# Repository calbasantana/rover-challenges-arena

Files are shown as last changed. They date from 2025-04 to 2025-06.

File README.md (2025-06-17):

# Introduction

<p align="center">
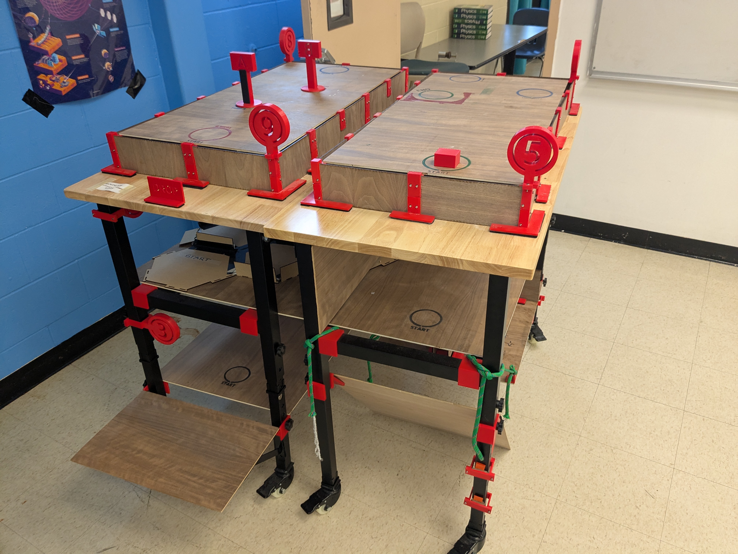
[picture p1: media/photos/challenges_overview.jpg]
Challenges Overview

</p>

Over the past year, I have modified my introductory physics curriculum after experiencing FIRST Lego League (FLL) through the lens of a coach. In FLL, students are tasked with completing a series of challenges, for which they earn points, using a Lego robot in autonomous mode. In previous years, students had constructed a rover capable of navigating autonomously and completed one of the challenges laid out here (challenge 4 -- the maze challenge).

Now, however, thanks to my FLL experiences, I have expanded from one challenge to ten total challenges. This resulted in the creation of a Rover Challenges Arena, which will be described here in detail. Specifically, I will highlight:

* The construction of the arena
* The challenges themselves

Below you will find resources associated with this course and repository.

**Associated Resources**:
* [Introductory Physics Google Drive folder](https://drive.google.com/drive/folders/14O6FQSpFUbI4DR4CiFaPI4PMuGjOlXuQ?usp=drive_link)
* [Rover Repository](https://github.com/calbasantana/rover)

# Challenges Arena Construction
The Challenges Arena was constructed with the aid of a lasercutter, 3D printer, and hand saw. Below you will find the complete list of materials used.

## Material(s)

**Challenges Arena**

* [2 48" Heavy-Duty Workbenches ($134.99 each, $269.98 total)](https://www.amazon.com/Betterhood-Heavy-Duty-Adjustable-Workstation-Wheels/dp/B09VXCW6VS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)
* [4 Sets of 8-Pack 12" x 16" x 1/8" Walnut Plywood Sheets ($32.99 each, or $131.96 total)](https://www.amazon.com/ROBOTIME-16-Pack-Walnut-Plywood-Sheets/dp/B0D4QWKYR7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)
* [4 True Red ELEGOO 1kg, 1.75mm Filament ($17.99 each, or $71.96 total)](https://www.amazon.com/ELEGOO-Filament-Dimensional-Accuracy-Printers/dp/B0D41ZDXLR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)
* [3 PureBond 4' x 4' Walnut Plywood Project Panels ($86.99 each, or $260.67 total)](https://www.homedepot.com/p/Columbia-Forest-Products-1-4-in-x-4-ft-x-4-ft-PureBond-Walnut-Plywood-Project-Panel-Free-Custom-Cut-Available-2328/204635499)
* [1/8" 11" x 17" Corrugated Cardboard Sheets ($29.99)](https://www.amazon.com/Golden-State-Art-Corrugated-Cardboard/dp/B09KYGZX8F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)
* [3 Sets of Double-Sided 1" x 4" Double-Sided Adhesive Strip ($11.39 each, or $34.17 total)](https://www.amazon.com/Art3d-Sticky-Double-Sided-Command-Adhesive/dp/B0B58FKYR2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)
* [Braided Rope ($9.99)](https://www.amazon.com/MaxxHaul-50227-Strength-Sunlight-Resistant-Multicolor/dp/B07X64Z69L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)
* [2 Triangle Shelf Brackets ($9.49)](https://www.amazon.com/Dewell-Triangle-Brackets-Mounted-Supports/dp/B07QLK6PWS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)

**Challenge 2: How Far? Surface Friction Materials**

For Challenge 2: How Far?, I also bought two types of materials, which I cut up and attached using velcro to the inner sides of the challenge to simulate friction versus different materials. I left a few sheets of each material as spare material for students to use for finding the coefficients of friction. Here is what I bought:

* [8.5"x11" 1/8" Thick Corrugated Cardboard Sheets ($14.89)](https://www.amazon.com/Corrugated-Cardboard-Shipping-Cushioning-Packing/dp/B09JQ6KPGB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)
* [9"x11" 120 Grit Sandpaper Sheets ($12.42)](https://www.amazon.com/Sungold-Abrasives-11108-Stearated-Aluminum/dp/B005YUJM3C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)
* [VELCRO Fasteners ($18.89)](https://www.amazon.com/VELCRO-Brand-Sticky-Fasteners-Perfect/dp/B000GRBEK2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)

Please note that I did three strips of Velcro, as shown below:

<p align="center">
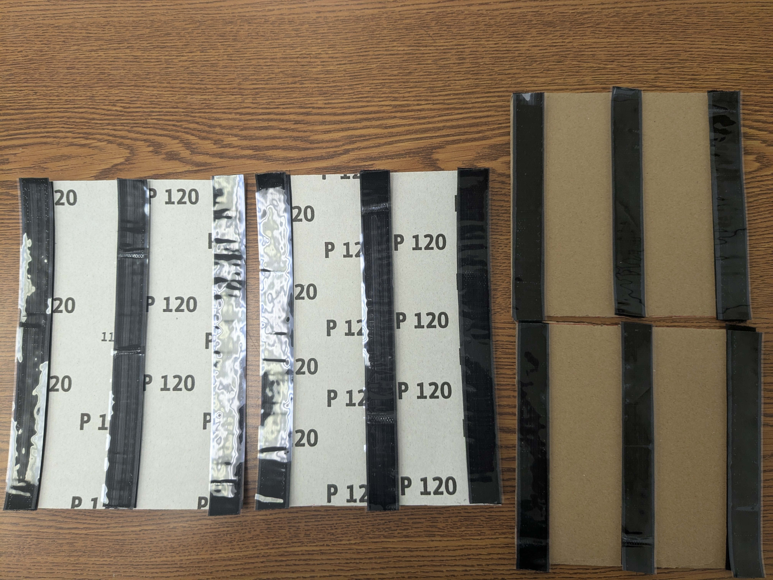
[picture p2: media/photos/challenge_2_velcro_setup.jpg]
Challenge 2 Velcro Setup

</p>

**Challenge 5: Surface Navigation Terrain**

For Challenge 5: Surface Navigation, I made a model of the lunar surface because I wanted students to experience navigating difficult terrain; to create this, I used the following materials:

* [10lb Large Black Lava Rocks ($29.99)](https://www.amazon.com/Onlyfire-Granules-Decorative-Outdoor-Fireplaces/dp/B0BPL24PYG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)
* [5 Bags of Medium (1/2" - 1") Lava Rocks ($12.35 each, or $61.75 total)](https://www.amazon.com/American-Fireglass-Medium-Lava-Rock/dp/B002NHW0NS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)
* [5 Bags of 4 lb Organic Whole Grain Buckwheat Flour ($20.99 each, or $104.95 total)](https://www.amazon.com/Organic-Buckwheat-Flour-Pounds-Unbleached/dp/B074S7NVH7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)
* [10 lb Unbleached All Purpose Flour ($10.49)](https://www.amazon.com/Gold-Medal-Unbleached-Flour-160-Ounce/dp/B0032A0G3G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)
* [4 Bags of 1.5lb Gray Unity Sand ($16.99 each, or $67.96 total)
](https://www.amazon.com/Sandsational-Sand-1-5-Colored-Weddings-Filler/dp/B00GMRPU46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)

**Screws and Nuts**

* [M3 x 10mm Socket Head Cap Screws ($7.69)](https://www.amazon.com/Fullerkreg-Socket-Stainless-Machine-Quantity/dp/B07CK3RSN3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)
* [M3 Locknuts ($5.99)](https://www.amazon.com/M3-Locknuts-Self-Lock-Stainless-Self/dp/B0D146SHYF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)

**Spray Painting**

I decided to use spray paint for the stencils, although in retrospect, it may have been easier to use acrylic paint since many of the numbers didn't come out as well as I wanted to. Here is the spray painting equipment I used:

* [Rust-Oleum Black Camouflage Spray Paint ($6.98)](https://www.homedepot.com/p/Rust-Oleum-Specialty-12-oz-Black-Camouflage-Spray-Paint-279179/326885188)
* [Rust-Oleum Gloss Colonial Red Spray Paint ($6.48)](https://www.homedepot.com/p/Rust-Oleum-Painter-s-Touch-2X-12-oz-Gloss-Colonial-Red-General-Purpose-Spray-Paint-334030/307244800)
* [Rust-Oleum Gloss Hunter Green Spray Paint ($6.48)](https://www.homedepot.com/p/Rust-Oleum-Painter-s-Touch-2X-12-oz-Gloss-Hunter-Green-General-Purpose-Spray-Paint-334034/307244781)
* [Rust-Oleum Satin Ink Blue Spray Paint ($6.48)](https://www.homedepot.com/p/Rust-Oleum-Painter-s-Touch-2X-12-oz-Satin-Ink-Blue-General-Purpose-Spray-Paint-334093/307244914)
* [3M Professional Paint Spray Respirator Medium ($48.98)](https://www.homedepot.com/p/3M-Professional-Paint-Spray-Respirator-Medium-7512PA1-A-PS/202077812)

## CAD Model

<p align="center">
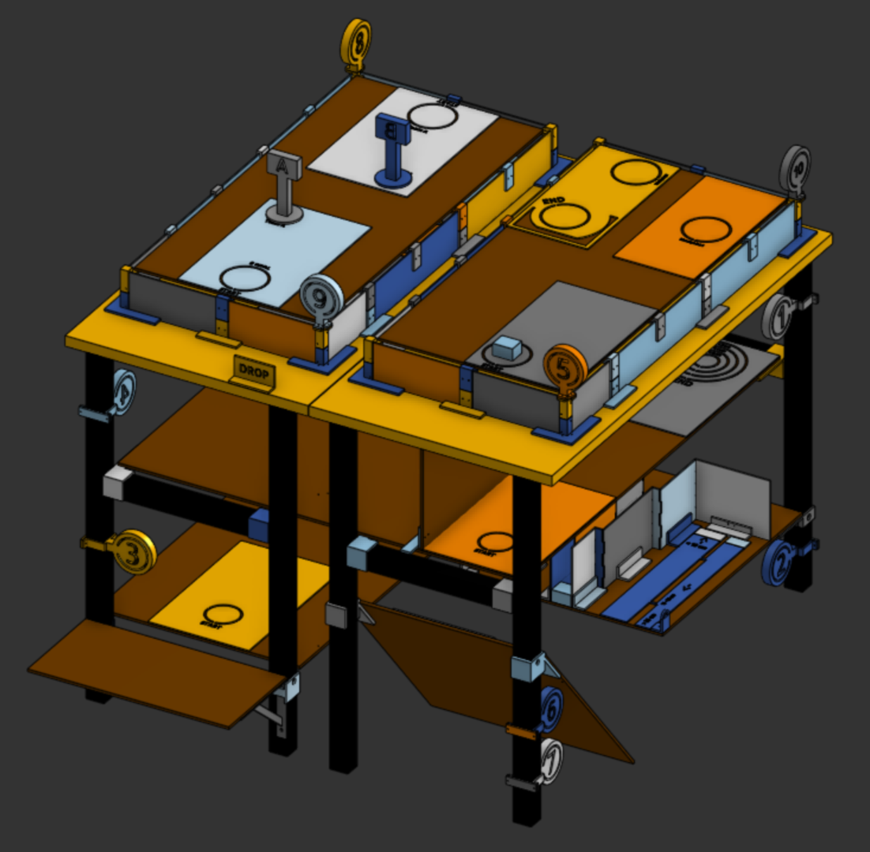
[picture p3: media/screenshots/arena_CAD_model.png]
Challenges Arena CAD Model

</p>

The fully completed CAD model is included above. It is important to note that there are over 150 parts to this design, so there will be a lot that needs to be lasercut and 3D printed. It is my largest project as of writing. Nevertheless, I do hope that the organization of the folders will make it easier to manufacture the components for this.

## 3D-Printed Parts
All parts that need to be 3D printed will be inside folders called "3D Prints", which will be inside each of the challenge's main folder.

### 3D Printing Process
The 3D printing process is quite lengthy given the large number of parts. However, expect around ~3 weeks of continuous printing to print all parts necessary for this project. The material used was included the previous materials section (True Red PLA from ELEGOO). Below you will find more information regarding the printer and settings used.

#### 3D Printer
Original Prusa Mini+

#### Software
PrusaSlicer

#### Settings
Layer Height: .2mm \
Infill: 50% \
Supports: Everywhere \
Estimated Printing Time: ~ 3 weeks.

## Laser Cut Parts
For the laser cut parts, which can be found in two separate folders -- "Laser Cuts" for parts that will be cut from the walnut sheets and "Stencils" for those that will be cut from the cardboard sheets -- are inside each of the challenge's main folder.

### Laser Cutting Process
Luckily, it is much quicker to fully cut all parts that need to be laser cut for this challenges arena. Make sure to remember to use cardboard for the stencils.

#### Lasercutter
XTool D1 Pro

#### Software
XTool Creative Studio (XCS)

#### Settings (for cutting)
Power (%): 100 \
Speed (mm/s): 5 \
Pass: 1

## Hand Sawn Parts
The last set of parts are those that need to be sawn. I purchased the large walnut sheets from Home Depot and got someone there to saw most of them for me. For the small parts, I used a hand saw. Below are the dimensions required:

* 1 44" x 40"
* 1 44" x 20"
* 1 44" x 10"
* 2 38" x 18.5"
* 2 24" x 20"
* 1 20" x 10"

Once you have finished these parts, you will be ready to use the stencils and spray paint.

## Stencils and Spray Painting

<p align="center">
  Spray Painting Photo 1
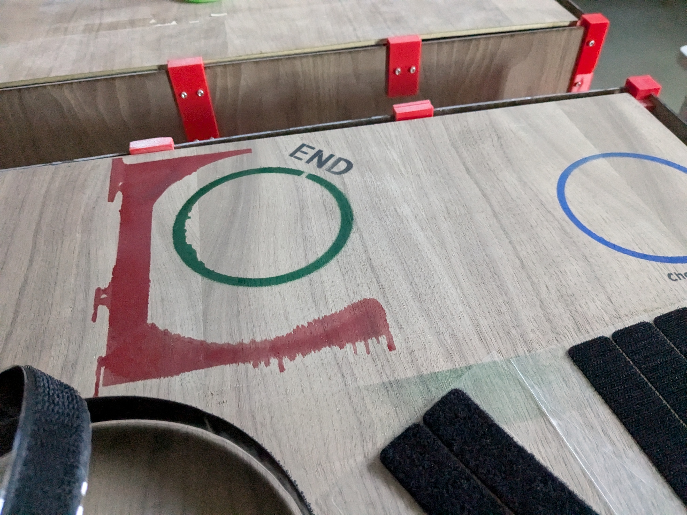
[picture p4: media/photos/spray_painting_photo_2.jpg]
Spray Painting Photo 2
  
</p>

For spray painting, I went outside on a nice cool day and began color coding things. You might do things differently, but you can tell from the pictures of the challenges how I decided to color things. In retrospect, as I mentioned before, I think I should have opted for acrylic paint because some of the spray paint didn't stick too well or bled out too much into the wood grain.

## Assembly
Once all parts have been completed and relevant parts spray painted, it's time for assembly. I highly suggest building the middle layer first so you can connect the large walnut sheet across both tables, which will provide some stability as you go on to assemble the rest. I expct assembly to take a full day or two given all the parts and screwing of components required.

For Challenge 5: Surface Navigation, I recommend adding some tape along the walls so the mixture doesn't seep through easily. You can include as many or as few rocks as you would like. I recommend using the medium-sized rocks all throughout the surface and the larger rocks for Challenge 1: Hercules's Push and maybe a few spread out on the Challenge 5: Surface Navigation.

# Challenges Overview
This part is the most relevant for students as it relates to what each challenge is specifically asking, so some students viewing this repository might want to skip to this section. For each challenge, there is an **Engineering Component** and a **Physics Component**. Students will be awarded points based on both the physical completion of the challenge (the former) and the completion of the mini-lab associated with it (the latter).

**IMPORTANT**: Students are required to complete a minimum of two **engineering components** and two **physics components** successfully. This should be done in the following manner, assuming students A, B, C, and D are in a group together.

**Challenge 1**

* Students A and B complete the engineering component together.
* Students C and D complete the physics component together.

**Challenge 2**

* Students C and D complete the engineering component together.
* Students A and B complete the physics component together.

Essentially, each pair of students will each complete one engineering component together and one physics component together. Students will receive credit for the engineering component they completed with their primary partner.

A complete description of each challenge will be found below. Please note that the maximum number of points possible is 800, but teams average around 100-200 historically.

## Challenge 1: Hercules's Push

<p align="center">
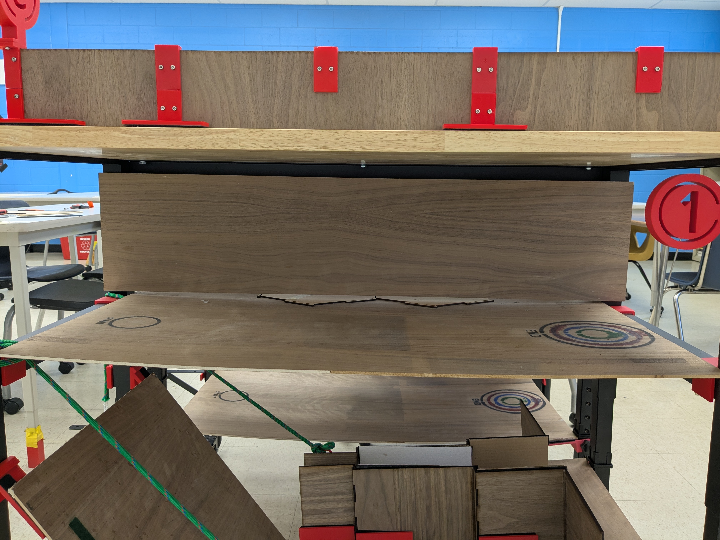
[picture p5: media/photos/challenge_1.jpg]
Challenge 1

</p>

**Engineering Component**

For this challenge, students are tasked with pushing a lava rock from one end of the field to the other. Points are determined based on accuracy to the target location as shown below:

| Distance from Target | Points Awarded |
| --- | --- |
| Not Attempted  | 0  |
| <2cm  | 20  |
| <4cm  | 15  |
| <6cm  | 5  |

**Physics Component**

This challenge requires students to be familiar with kinematics (as well as forces) concepts and coding in micropython, as they will be required to:

* Program their rover so that it has constant acceleration
* Use a kinematic equation to determine the push and net accelerations of their rover
* Create force diagrams for the lava rock
* Determine force of friction on the lava rock

More details on how students are graded for this can be found in the assignment itself, which is under Documents in Challenge 1: Hercules's Push folder. The document is listed as docx and PDF files.

The grading rubric, which is the same for all challenges, is included below:

| Proficiency Level | Points Awarded | Grade |
| --- | --- | --- |
| **Not Yet**: You have not correctly completed any of the elements of this challenge component. | 0 | 50% |
| **Approaching Proficiency**: You have correctly completed at least one element of this challenge component. | 10 | 60% |
| **Somewhat Proficient**: You have correctly completed half of the elements of this challenge component. | 20 | 70% |
| **Proficient**: You have correctly completed all of the elements of this challenge component. | 30 | 85% |
| **Exceeding Proficiency**: You have additionally and correctly completed the independent element of this challenge component.  | 40 | 100% |

**Student Example**

This was a very easy challenge for most students to complete, so you will be able to see two video examples below (as well as under media/videos).

https://github.com/user-attachments/assets/afdffd39-8b7c-4cd7-a783-8676905cb639

https://github.com/user-attachments/assets/8b72730f-63d5-43e9-9725-9e6176717091

## Challenge 2: How Far?

<p align="center">
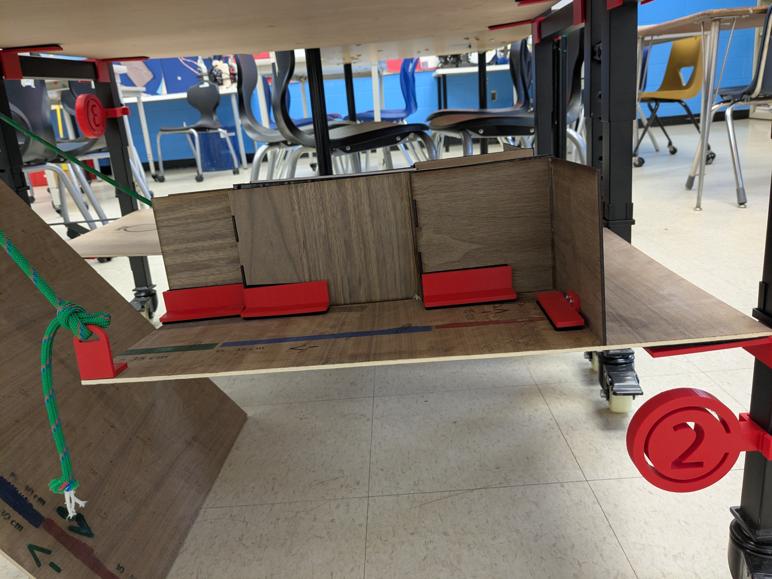
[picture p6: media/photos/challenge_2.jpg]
Challenge 2

</p>

**Engineering Component**

This can be one of the trickier challenges to complete depending on how you do it. It requires students to design the rover such that it can push a 3cm x 4cm x 5cm box through an increasingly smaller opening. The first opening is 13cm wide, the second is 9cm wide, and the last is 5cm wide. It must go all the way through and push the box over the edge on the smaller side of the challenge field. Depending on how far you make it, you will be awarded a different number of points, as shown below.

| Distance Traveled | Points Awarded |
| --- | --- |
| Not Attempted  | 0 |
| <15cm  | 20 |
| 15-30cm  | 15 |
| >30cm  | 5 |

**Physics Component**

This challenge requires students to be familiar with forces concepts and coding in micropython, as they will be required to:

* Determine coefficient of friction between their rover material and challenge-specific materials
* Answer questions about friction

More details on how students are graded for this can be found in the assignment itself, which is under Documents in Challenge 2: How Far? folder. The document is listed as docx and PDF files.

The grading rubric, which is the same for all challenges, is included below:

| Proficiency Level | Points Awarded | Grade |
| --- | --- | --- |
| **Not Yet**: You have not correctly completed any of the elements of this challenge component. | 0 | 50% |
| **Approaching Proficiency**: You have correctly completed at least one element of this challenge component. | 10 | 60% |
| **Somewhat Proficient**: You have correctly completed half of the elements of this challenge component. | 20 | 70% |
| **Proficient**: You have correctly completed all of the elements of this challenge component. | 30 | 85% |
| **Exceeding Proficiency**: You have additionally and correctly completed the independent element of this challenge component.  | 40 | 100% |

**Student Example**

For this challenge, you can see below and under media/videos how a team of students was able to complete it. However, please note that students will no longer be allowed to use an additional field to extend the length and reach of their attachments.

https://github.com/user-attachments/assets/25190a58-6e21-4ddf-ae70-2b8eacff4d61

## Challenge 3: A Rocky Landing

<p align="center">
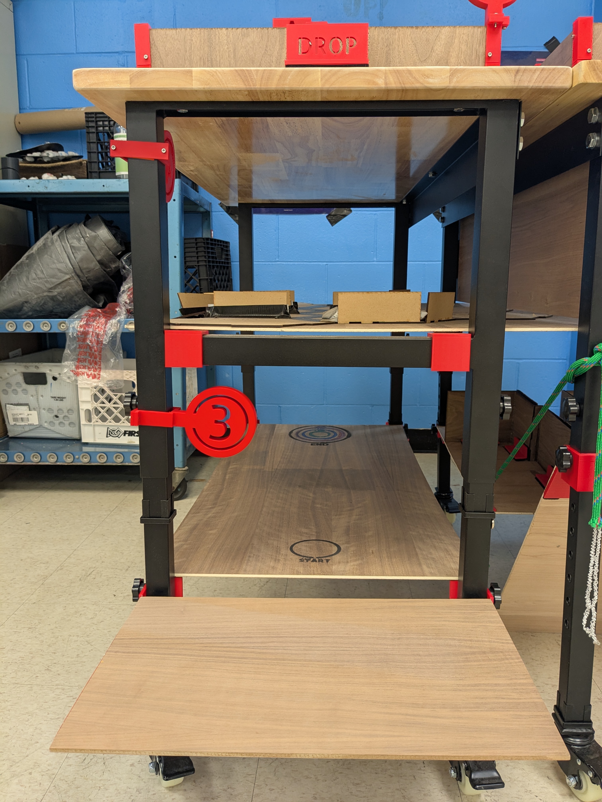
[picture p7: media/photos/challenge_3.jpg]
Challenge 3

</p>

**Engineering Component**

This is the one challenge that very few students have attempted and none have succeeded as of writing this. It requires for the rover to be dropped from a height of approximately .75 meters and subsequently navigate to a target location. Points are awarded based on accuracy of the location to the target as shown below.

| Distance from Target | Points Awarded |
| --- | --- |
| Not Attempted  | 0 |
| <2cm  | 20 |
| <4cm  | 15 |
| <6cm  | 5 |

**Physics Component**

This challenge requires students to be familiar with energy and law of conservation of energy concepts and coding in micropython, as they will be required to:

* Calculate gravitational potential energy and kinetic energy
* Determine how much energy the rover system would need to absorb
* Answer questions about energy

More details on how students are graded for this can be found in the assignment itself, which is under Documents in Challenge 3: A Rocky Landing folder. The document is listed as docx and PDF files.

The grading rubric, which is the same for all challenges, is included below:

| Proficiency Level | Points Awarded | Grade |
| --- | --- | --- |
| **Not Yet**: You have not correctly completed any of the elements of this challenge component. | 0 | 50% |
| **Approaching Proficiency**: You have correctly completed at least one element of this challenge component. | 10 | 60% |
| **Somewhat Proficient**: You have correctly completed half of the elements of this challenge component. | 20 | 70% |
| **Proficient**: You have correctly completed all of the elements of this challenge component. | 30 | 85% |
| **Exceeding Proficiency**: You have additionally and correctly completed the independent element of this challenge component.  | 40 | 100% |

**Student Example**

At time of writing, there has yet to be a team to complete this challenge. It is incredibly difficult.

## Challenge 4: A Way Out

<p align="center">
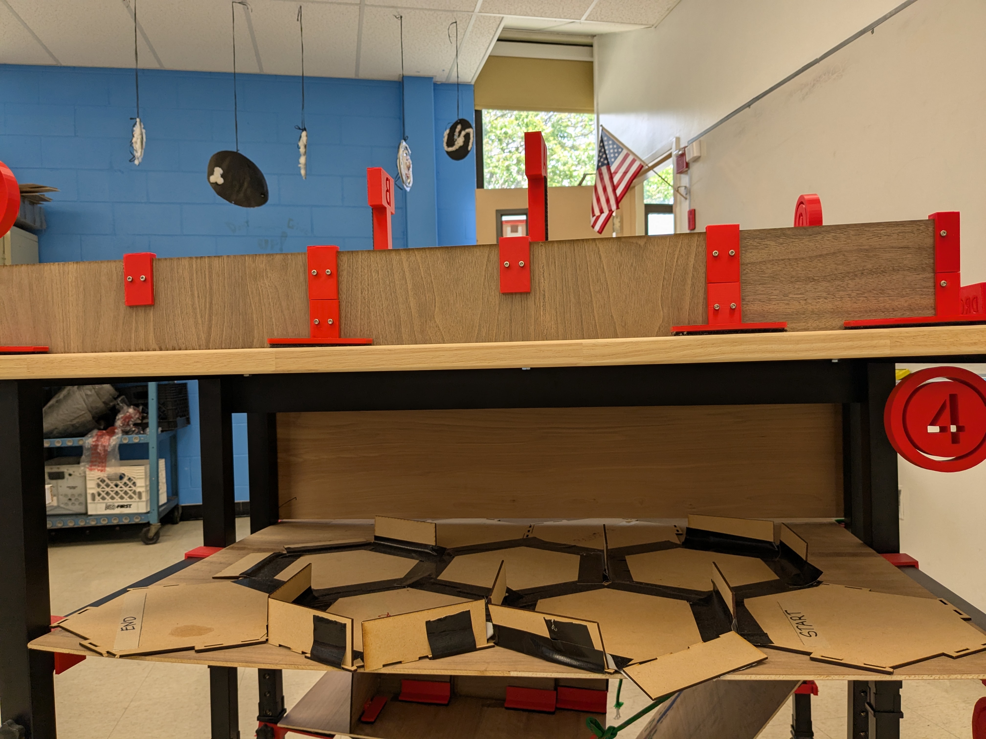
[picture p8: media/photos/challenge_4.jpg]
Challenge 4

</p>

**Engineering Component**

This challenge is different than the previous challenges because points are awarded based on the completion of certain tasks, rather than accuracy. Specifically, students are required to navigate a maze and will only receive points if they complete the maze. They will receive additional points if they have their rover pass through "Bonus" sections. Below is a breakdown of the number of points per task.

| Task | Points Awarded |
| --- | --- |
| Not Attempted  | 0 |
| Maze Completion  | 30 |
| Bonus 1  | 15 |
| Bonus 2  | 15 |

Please note that this means, based on the engineering component alone, students can earn up to 60 points, much greater than the previous challenges's engineering components.

**Physics Component**

This challenge requires students to be familiar with kinematics concepts and coding in micropython, as they will be required to:

* Determine the total distance traveled by their rover
* Determine the average speed of their rover
* Determine the displacement of their rover
* Determine the average velocity of their rover

More details on how students are graded for this can be found in the assignment itself, which is under Documents in Challenge 4: A Way Out folder. The document is listed as docx and PDF files.

The grading rubric, which is the same for all challenges, is included below:

| Proficiency Level | Points Awarded | Grade |
| --- | --- | --- |
| **Not Yet**: You have not correctly completed any of the elements of this challenge component. | 0 | 50% |
| **Approaching Proficiency**: You have correctly completed at least one element of this challenge component. | 10 | 60% |
| **Somewhat Proficient**: You have correctly completed half of the elements of this challenge component. | 20 | 70% |
| **Proficient**: You have correctly completed all of the elements of this challenge component. | 30 | 85% |
| **Exceeding Proficiency**: You have additionally and correctly completed the independent element of this challenge component.  | 40 | 100% |

**Student Example**

Unfortunately, I do not presently have a video to show here, but one team has completed this challenge in the past. Please note that the most difficult element of completing this challenge is the coding, which will require a lot of trial and error.

## Challenge 5: Surface Navigation

<p align="center">
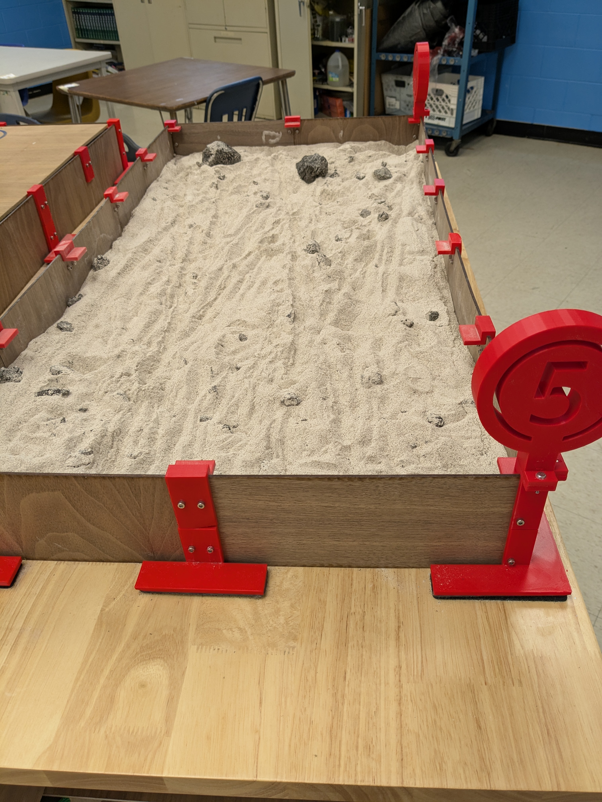
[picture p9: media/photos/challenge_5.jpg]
Challenge 5

</p>

**Engineering Component**

This challenge requires students to design their rover such that it can navigate from one end of the field to the other. Most rovers are designed in such a way that this is very difficult and a lot of teams design custom wheels to support them in completing this challenge. Like the previous challenge, this challenge's points are awarded based on the completion of certain tasks, which will be shown in the rubric below.

| Task | Points Awarded |
| --- | --- |
| Not Attempted  | 0 |
| Navigate to End  | 30 |
| Carry 1 Large Lunar Rock  | 15 |
| Carry 1 Large Lunar Rock  | 15 |

As noted in the previous challenge, this means that a team can earn up to 60 points for navigating from one end to another and carrying two lunar rocks (which are really just the lava rocks from the materials section of the arena).

**Physics Component**

This challenge requires students to be familiar with kinematics concepts and coding in micropython, as they will be required to:

* Determine the displacement of their rover
* Determine the average velocity of their rover
* Determine the acceleration of their rover

More details on how students are graded for this can be found in the assignment itself, which is under Documents in Challenge 5: Surface Navigation folder. The document is listed as docx and PDF files.

The grading rubric, which is the same for all challenges, is included below:

| Proficiency Level  | Points Awarded | Grade |
| --- | --- | --- |
| **Not Yet**: You have not correctly completed any of the elements of this challenge component. | 0 | 50% |
| **Approaching Proficiency**: You have correctly completed at least one element of this challenge component. | 10 | 60% |
| **Somewhat Proficient**: You have correctly completed half of the elements of this challenge component. | 20 | 70% |
| **Proficient**: You have correctly completed all of the elements of this challenge component. | 30 | 85% |
| **Exceeding Proficiency**: You have additionally and correctly completed the independent element of this challenge component.  | 40 | 100% |

**Student Example**

Below and under media/videos you will find a video of how a team completed the engineering component of this challenge.

https://github.com/user-attachments/assets/06d660ac-c105-4a08-b690-703fcb1c7aff

## Challenge 6: Welcome to Seattle

<p align="center">
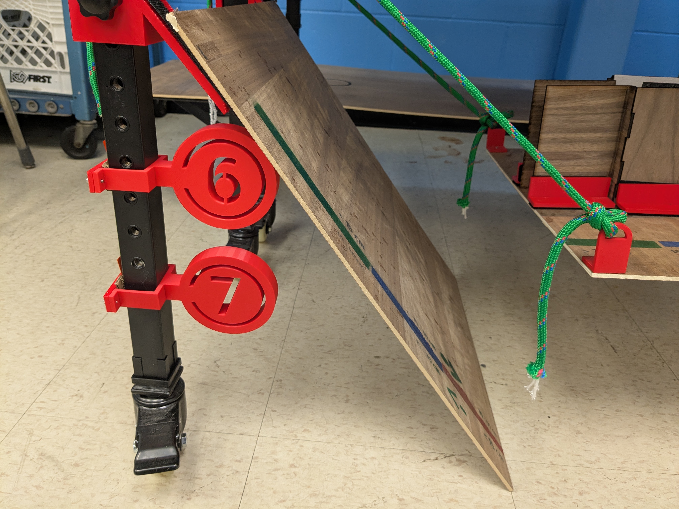
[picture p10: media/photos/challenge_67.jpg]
Challenges 6 and 7

</p>

**Engineering Component**

Seattle is known for being a hilly city and on an escapade a few years back, I learned the lesson the hard way. For this challenge, students are required to have their rover move up a steep incline. They will be awarded points based on how far their rover makes it up the incline; for some rovers, they will only make it part of the way up and then they will fall backwards and for others they will make it over quite easily and fall forward. Either way, points are awarded as shown below.

| Distance Traveled | Points Awarded |
| --- | --- |
| Not Attempted  | 0 |
| <15cm  | 20 |
| 15-30cm  | 15 |
| >30cm  | 5 |

**Physics Component**

This challenge requires students to be familiar with forces concepts primarily, as they will be required to:

* Determine the maximum angle at which their rover can stay still on an incline
* Determine the values of all forces on their rover on an incline plane

More details on how students are graded for this can be found in the assignment itself, which is under Documents in Challenge 6: Welcome to Seattle folder. The document is listed as docx and PDF files.

The grading rubric, which is the same for all challenges, is included below:

| Proficiency Level  | Points Awarded | Grade |
| --- | --- | --- |
| **Not Yet**: You have not correctly completed any of the elements of this challenge component. | 0 | 50% |
| **Approaching Proficiency**: You have correctly completed at least one element of this challenge component. | 10 | 60% |
| **Somewhat Proficient**: You have correctly completed half of the elements of this challenge component. | 20 | 70% |
| **Proficient**: You have correctly completed all of the elements of this challenge component. | 30 | 85% |
| **Exceeding Proficiency**: You have additionally and correctly completed the independent element of this challenge component.  | 40 | 100% |

**Student Example**

As of yet, there has not been a single team who has completed this challenge, though many have tried; unfortunately, there is no student example to show here.

## Challenge 7: Down the Canyon

<p align="center">
Challenges 6 and 7
</p>

**Engineering Component**

This challenge is a sister challenge to the previous in that it is using the same arena, but instead of going up the incline, you are going down the incline. The trick here is ensuring that your rover does not slip and fall as it is going down. Points will also be awarded in a similar way, but it is distance from the top to the bottom; see the rubric below for the breakdown and specifics.

| Distance Traveled | Points Awarded |
| --- | --- |
| Not Attempted  | 0 |
| <15cm  | 20 |
| 15-30cm  | 15 |
| >30cm  | 5 |

**Physics Component**

Like the previous challenge, students will need to be familiar with forces primarily because this challenge will require them to:

* Determine the value of the friction force on your rover on an incline plane
* Determine the work done by friction

More details on how students are graded for this can be found in the assignment itself, which is under Documents in Challenge 1: Hercules's Push folder. The document is listed as docx and PDF files.

The grading rubric, which is the same for all challenges, is included below:

| Proficiency Level  | Points Awarded | Grade |
| --- | --- | --- |
| **Not Yet**: You have not correctly completed any of the elements of this challenge component. | 0 | 50% |
| **Approaching Proficiency**: You have correctly completed at least one element of this challenge component. | 10 | 60% |
| **Somewhat Proficient**: You have correctly completed half of the elements of this challenge component. | 20 | 70% |
| **Proficient**: You have correctly completed all of the elements of this challenge component. | 30 | 85% |
| **Exceeding Proficiency**: You have additionally and correctly completed the independent element of this challenge component.  | 40 | 100% |

**Student Example**

I currently do not have a video of this challenge being completed, but one group has completed in the past and three have attempted it.

## Challenge 8: Giving a Gift

<p align="center">
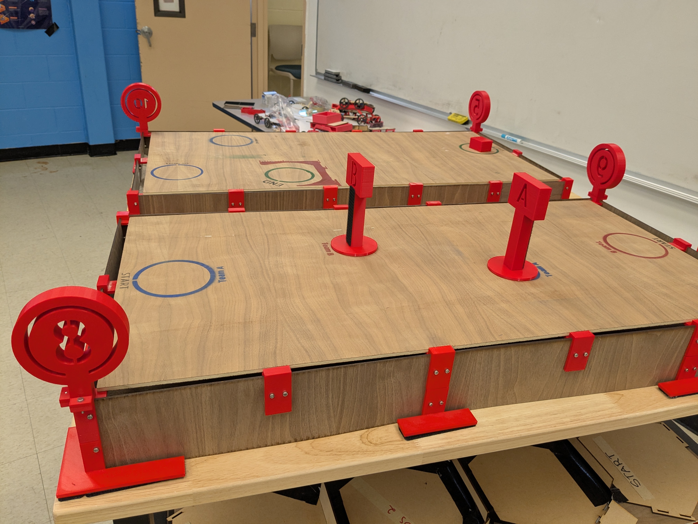
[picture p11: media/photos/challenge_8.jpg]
Challenge 8

</p>

**Engineering Component**

This, and the subsequent two challenges, are considered "competition"-style challenges. This means that students will compete against other teams; for two of these challenges, it will be in real time, but for the last one it will be in timed trials.

For this specific challenge, each team places their rover at either end of the field and they are tasked with pushing a flag of the opposing team into the opposing team's base. Essentially, students are tasked with returning flags to the opposing team or -- as the name suggests -- giving them a gift.

This challenge can only run if there are at least three teams taking part in it. If only one or two teams decide to take part, then it isn't much of a competition; for that reason, should there be fewer than three teams competing, then both teams, or the single team competing, will receive points that would typically be awarded to those in second place.

Based on placement in the competition, the points awarded will be as described in the table below.

| Placement | Points Awarded |
| --- | --- |
| Not Attempted | 0 |
| First Place | 60 |
| Second Place | 30 |
| Third Place | 15 |

**Physics Component**

This challenge requires students to be familiar with momentum (as well as the law of conservation of momentum) concepts and coding in micropython, as they will be required to:

* Determine initial momentum of the system
* Determine final momentum of the system
* Determine how much momentum is lost and why

However, students should note that -- at least in my classes -- momentum and the law of conservation of momentum are only covered in the honors version of the course, meaning that to complete the physics component of this challenge, if they do not have the prerequisite background, they will need to learn it on their own or with aid of PositivePhysics.

More details on how students are graded for this can be found in the assignment itself, which is under Documents in Challenge 1: Hercules's Push folder. The document is listed as docx and PDF files.

The grading rubric, which is the same for all challenges, is included below:

| Proficiency Level  | Points Awarded | Grade |
| --- | --- | --- |
| **Not Yet**: You have not correctly completed any of the elements of this challenge component. | 0 | 50% |
| **Approaching Proficiency**: You have correctly completed at least one element of this challenge component. | 10 | 60% |
| **Somewhat Proficient**: You have correctly completed half of the elements of this challenge component. | 20 | 70% |
| **Proficient**: You have correctly completed all of the elements of this challenge component. | 30 | 85% |
| **Exceeding Proficiency**: You have additionally and correctly completed the independent element of this challenge component.  | 40 | 100% |

**Student Example**

The last time I ran this, only one team decided to attempt the challenge, so this is the only available video of students completing this challenge that I have; please find this video below and under media/videos.

https://github.com/user-attachments/assets/4569af59-405b-4fd5-b390-9fb119e761e6

## Challenge 9: SUMO

<p align="center">
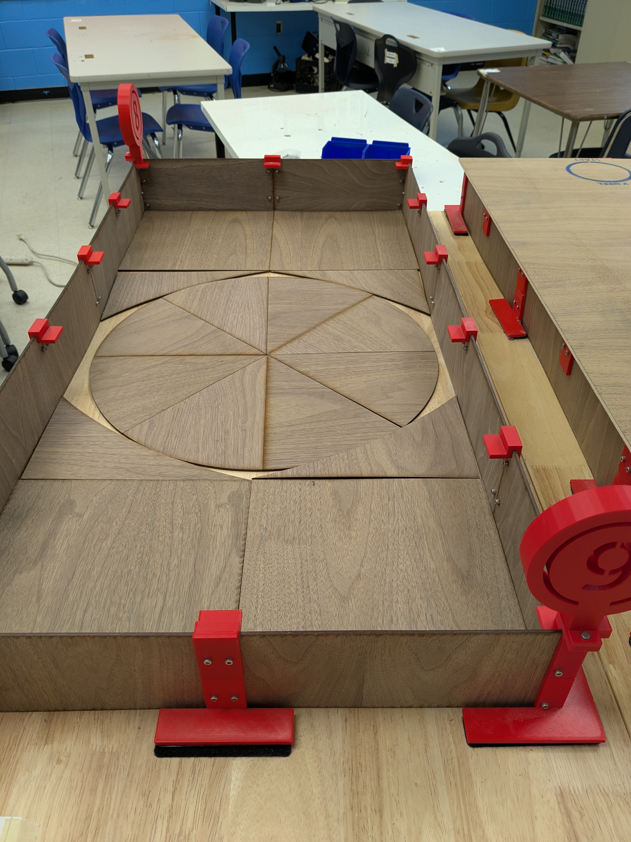
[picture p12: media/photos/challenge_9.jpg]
Challenge 9

</p>

**Engineering Component**

This is probably the most fun and engaging challenge of all; a lot of students choose to compete in this challenge. Much like the previous challenge, it requires a minimum of three teams; if two or fewer sign up, those who sign up will receive points as if they won second place.

For this challenge, the team's rover is required to push the opposing team's rover out of a ring. A team loses when they either get "stuck" on a part of the ring or their rear wheels go outside of the circle. It does not matter what happens after. For a breakdown of points, see the table below.

| Placement | Points Awarded |
| --- | --- |
| Not Attempted | 0 |
| First Place | 60 |
| Second Place | 30 |
| Third Place | 15 |

**Physics Component**

This challenge requires students to be familiar with forces primarily, as they will be required to:

* Collaborate with an opposing team to create a force diagram of your rover and the forces it experiences
* Determine how long it should take to win or lose
* Reflect on accuracy of your calculations

More details on how students are graded for this can be found in the assignment itself, which is under Documents in Challenge 1: Hercules's Push folder. The document is listed as docx and PDF files.

The grading rubric, which is the same for all challenges, is included below:

| Proficiency Level  | Points Awarded | Grade |
| --- | --- | --- |
| **Not Yet**: You have not correctly completed any of the elements of this challenge component. | 0 | 50% |
| **Approaching Proficiency**: You have correctly completed at least one element of this challenge component. | 10 | 60% |
| **Somewhat Proficient**: You have correctly completed half of the elements of this challenge component. | 20 | 70% |
| **Proficient**: You have correctly completed all of the elements of this challenge component. | 30 | 85% |
| **Exceeding Proficiency**: You have additionally and correctly completed the independent element of this challenge component.  | 40 | 100% |

**Student Example**

Below and under media/videos, you will see two of many videos I have of students competing in this challenge.

https://github.com/user-attachments/assets/32562579-a1fd-41d3-9cc3-c7402d23a0af

https://github.com/user-attachments/assets/70a44815-16cc-4bab-8fb9-d8a62cc48f33

## Challenge 10: Resupply Mission

<p align="center">
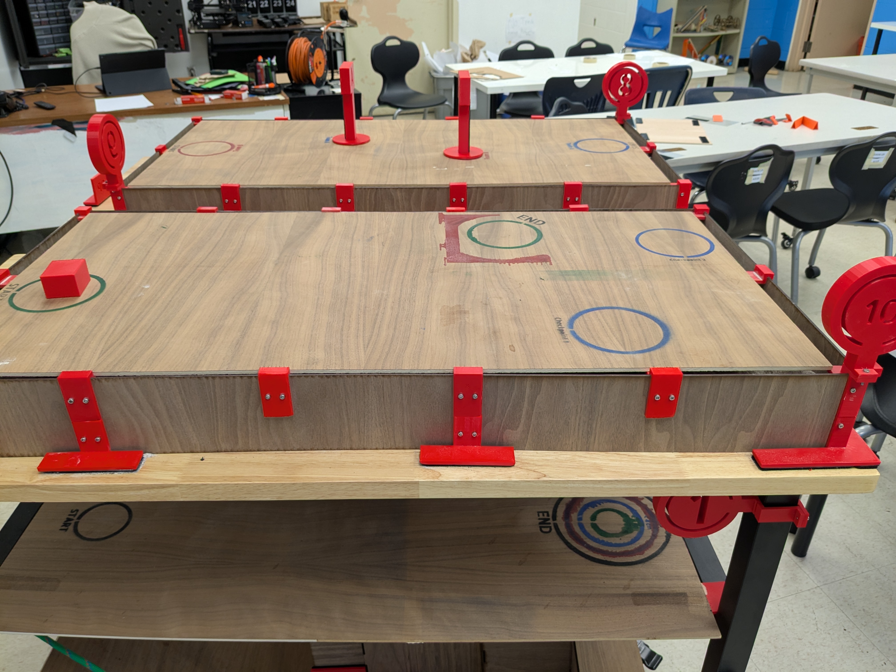
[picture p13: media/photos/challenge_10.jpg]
Challenge 10

</p>

**Engineering Component**

Like the previous two challenges, this last challenge is a "competition"-style challenge. However, what makes this one different than the other two is that it is timed asynchronous trials that will be used to determine placement rather than simultaneous competition.

For this challenge, students are required to have their rover push a box to an endpoint. This endpoint is considered the delivery point. However, students cannot go onto red-colored paint, so they must navigate around to reach the endpoint. The less time it takes for a team to do this, the better; the team with the shortest time to complete this task will receive first place.

However, as noted before, if two or fewer teams sign up for this challenge, then those who complete the challenge will automatically receive points that those who would receive second place in a competition would receive. If three or more teams sign up for this challenge, the points awarded will be the same as the previous competitions (shown below), based on placement.

| Placement | Points Awarded |
| --- | --- |
| Not Attempted | 0 |
| First Place | 60 |
| Second Place | 30 |
| Third Place | 15 |

**Physics Component**

This challenge requires students to be familiar with kinematics (as well as forces)concepts and coding in micropython, as they will be required to:

* Create constant acceleration program
* Create a force diagram for the supply box
* Determine the coefficient of friction of the supply box on the given surface
* Determine how long it should take to move the box to the desired location, based on net force

More details on how students are graded for this can be found in the assignment itself, which is under Documents in Challenge 1: Hercules's Push folder. The document is listed as docx and PDF files.

The grading rubric, which is the same for all challenges, is included below:

| Proficiency Level  | Points Awarded | Grade |
| --- | --- | --- |
| **Not Yet**: You have not correctly completed any of the elements of this challenge component. | 0 | 50% |
| **Approaching Proficiency**: You have correctly completed at least one element of this challenge component. | 10 | 60% |
| **Somewhat Proficient**: You have correctly completed half of the elements of this challenge component. | 20 | 70% |
| **Proficient**: You have correctly completed all of the elements of this challenge component. | 30 | 85% |
| **Exceeding Proficiency**: You have additionally and correctly completed the independent element of this challenge component.  | 40 | 100% |

**Student Example**

In the previous year, only one team signed up to complete this challenge and they were able to complete it successfully. However, I do not have a video of them completing it presently.

# Tips

There is a lot that can be improved regarding these challenges in terms of their physics content, engineering content, and especially the arena itself. Here are some tips that might be helpful.

**Building of the Rover Challenges Arena**

* You can use any type of velcro adhesive, even those that come in big packets and you cut up. It might be cheaper than buying the 1" x 4" strips.
* You do not need as many large lava rocks as I have on the materials list, but they are good in case you want to build something else.

**Challenges**

* Students are encouraged to seek innovative solutions, but it's also OK to rely on the success of previous teams.
* It is generally recommended to pair up challenges such that it is easier to complete and concepts are similar.

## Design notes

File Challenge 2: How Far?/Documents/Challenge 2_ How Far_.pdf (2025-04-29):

Name 1:

Name 2:

Date:

Challenge #2: How Far?

Overview

Up to two students can work on this challenge. Remember each team member must

contribute to at least one the completion of one of the physics components for one challenge and

the completion of one of the engineering components for another challenge. This challenge is

about forces. You will be asked to do the following:

1. Determine coefficient of friction between your rover material and challenge-specific

materials

2. Answer questions about friction

Your Rover Material

You generally have three options regarding the material construction of your rover,

laser-cut MDF wood, laser-cut cardboard, or 3D-printed PLA. Your rover’s exterior, may

however, be made of another material; regardless, please note the exterior material of your rover

that will be making contact with the interior of the tunnel.

Rover Shell Material:

Coefficient of Friction Review

Please remember that, to determine the coefficient of friction, you need to use the

following equation:

Ff=μFN

If you are doing your experiment on a flat surface, then the gravitational force of the

material on top (Fg=mg, where g=9.81 m/s²
) is equal to the normal force (FN). You can also push

one surface against the other, as we did in lab 3, to make sure that the net force experienced is

equal to the force of friction, such that:

Fnet=manet=Ff

In the equation above, m is the mass of the surface on top and the acceleration is

determined either using a kinematic equation or Vernier Video Analysis (the latter of which is

more ideal). You should then be able to determine your coefficient of friction with:

µ =

F
f
F
N
Coefficient of Friction Between Your Rover Material & Interior Material 1

After you have determined your rover shell material, it is time to determine the

coefficient of friction between it and the first interior material for the tunnel. The first layer of

the tunnel is made of cardboard.

In the space below, please draw a force diagram (or free body diagram) of your

experimental set-up to determine the coefficient of friction.

Use Vernier Video Analysis or a kinematic equation to determine your net acceleration

and write it below:

Acceleration (anet): ________

Then, determine the mass (in kg) of the surface on top and subsequently your force of

friction:

Mass (m): ________

Force of Friction (Ff): ________

Using the equation for gravitational force (Fg=mg, where g=9.81 m/s² ), determine your

normal force:

Normal Force (FN): ________

Using the equation for the force of friction (Ff=μFN), determine your coefficient of

friction between these two surfaces.

Coefficient of Friction (μ): ________

Coefficient of Friction Between Your Rover Material & Interior Material 2

You should now attempt to determine the coefficient of friction between your rover shell material

and the second interior material for the tunnel. The second layer of the tunnel is made of

sandpaper.

In the space below, please draw a force diagram (or free body diagram) of your

experimental set-up to determine the coefficient of friction.

Use Vernier Video Analysis or a kinematic equation to determine your net acceleration

and write it below:

Acceleration (anet): ________

Then, determine the mass (in kg) of the surface on top and subsequently your force of

friction:

Mass (m): ________

Force of Friction (Ff): ________

Using the equation for gravitational force (Fg=mg, where g=9.81 m/s² ), determine your

normal force:

Normal Force (FN): ________

Using the equation for the force of friction (Ff=μFN), determine your coefficient of

friction between these two surfaces.

Coefficient of Friction (μ): ________

Coefficient of Friction Between Your Rover Material & Interior Material 3

You should now attempt to determine the coefficient of friction between your rover shell material

and the third interior material for the tunnel. The third layer of the tunnel is made of walnut

plywood.

Exceeding Proficiency: If you determine the coefficient of friction on your own for this section,

and it is correct or reasonable, you will receive exceeding proficiency.

In the space below, please draw a force diagram (or free body diagram) of your

experimental set-up to determine the coefficient of friction.

Use Vernier Video Analysis or a kinematic equation to determine your net acceleration

and write it below:

Acceleration (anet): ________

Then, determine the mass (in kg) of the surface on top and subsequently your force of

friction:

Mass (m): ________

Force of Friction (Ff): ________

Using the equation for gravitational force (Fg=mg, where g=9.81 m/s² ), determine your

normal force:

Normal Force (FN): ________

Using the equation for the force of friction (Ff=μFN), determine your coefficient of

friction between these two surfaces.

Coefficient of Friction (μ): ________

Questions About Friction

There are two types of coefficients of friction, which are they?

Which type of coefficient of friction did you calculate?

Do you expect the coefficient of static friction or the coefficient of kinetic friction to be

higher?

Why did you answer the way you did to the previous question?

Point System (TEACHER ONLY - CIRCLE ONE)

Not Yet (0pts) (50%) | Approaching Proficiency (10pts) (60%) | Somewhat Proficient (20pts) (70%) | Proficient (30pts) (85%) | Exceeding Proficiency (40pts) (100%)
You have not correctly completed any of the elements of this challenge component. | You have correctly completed at least one element of this challenge component. | You have correctly completed half of the elements of this challenge component. | You have correctly completed all of the elements of this challenge component. | You have additionally and correctly completed the independent element of this challenge component.

Comments:

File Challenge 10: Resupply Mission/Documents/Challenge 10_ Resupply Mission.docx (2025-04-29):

Name 1:

Name 2:

Date:

## Challenge #10: Resupply Mission

Overview

Up to two students can work on this challenge. Remember each team member must contribute to at least one the completion of one of the physics components for one challenge and the completion of one of the engineering components for another challenge. This challenge is primarily about kinematics. You will be asked to do the following:

1. Create constant acceleration program
2. Create a force diagram for the supply box
3. Determine the coefficient of friction of the supply box on the given surface
4. Determine how long it should take to move the box to the desired location, based on net force

Programming

To create a program that has a constant acceleration, you must increase its speed at the same rate. To do this, please use the program template below; feel free to modify the “step” size of 100 and the time between steps of 0.5.

for i in range(100,900, +100):

MD1.forwardMOT12(i)

MD2.forwardMOT34(i)

sleep(0.5)

MD1.stopMOT12()

MD2.stopMOT34()

Determining Push and Net Accelerations

Prior to creating a force diagram for the supply box, it is important that you determine your push and net accelerations. The best way to determine the accelerations of your rover is by using Vernier Video Analysis. Make sure to get steady videos with a meter stick in front and that this is on the actual test surface. First, obtain a video without the supply box and then a video with the supply box. Fill out the corresponding sections.

Determining Push Acceleration (No Supply Box)

When you are analyzing the video on Vernier Video Analysis, look at your X Velocity (m/s) vs. Time (s) graph. If you need help to access this graph, please ask your teacher. Select two points that lie on a straight line and determine push acceleration. Make sure to write down:

Initial Velocity (v0): ________

Final Velocity (v): ________

Time (t): ________

Acceleration (apush): ________

Determining Net Acceleration (With Supply Box)

When you are analyzing the video on Vernier Video Analysis, look at your X Velocity (m/s) vs. Time (s) graph. If you need help to access this graph, please ask your teacher. Select two points that lie on a straight line and determine net acceleration. Make sure to write down:

Initial Velocity (v0): ________

Final Velocity (v): ________

Time (t): ________

Acceleration (anet): ________

Force Diagram (or Free Body Diagram)

To create a force diagram, first write down all of the forces present below.

In the space provided draw your force diagram and make sure the magnitude of the forces are relative to each other. Please also include the net force in your force diagram.

Determining Drag or Friction Force

You can determine the force of the push using Newton’s second law (with the mass of the rover). Remember that you know the net force on the supply box as well, which means you can calculate the friction force or drag force on the supply box (hint: Fnet=Fapplied-Ff). Use the space below to write down your calculations and write the final value for the friction force.

Friction Force (Ff): ________

Coefficient of Friction (μ): ________

Exceeding Proficiency: If you, additionally, determine the theoretical time to the desired location on your own, and it is correct or reasonable, you will receive exceeding proficiency.

Theoretical Time to the Desired Location

Rewrite your calculated net acceleration from Vernier Video Analysis below . Remember that you will be starting from rest and measure the distance from the side of the supply box closest to the rover to the desired location and write it below.

Acceleration (anet): ________

Initial Velocity (v0): ________

Distance to Desired Location (Δx): ________

Using a kinematic equation, determine the time you would expect for the supply box to reach the desired location. Include your work in the space below.

Time to Desired Location (t): ________

Experimental Time to Desired Location

Now, starting from the same place, experimentally measure – four times – the time to the desired location and complete the table below.

Trial | Time(s)
Average Time:

How does the experimental time compare to the theoretical time from the previous section?

What might be some sources of error that would lead to a difference between the two times?

Point System (TEACHER ONLY - CIRCLE ONE)

Not Yet (0pts) (50%) | Approaching Proficiency (10pts) (60%) | Somewhat Proficient (20pts) (70%) | Proficient (30pts) (85%) | Exceeding Proficiency (40pts) (100%)
You have not correctly completed any of the elements of this challenge component. | You have correctly completed at least one element of this challenge component. | You have correctly completed half of the elements of this challenge component. | You have correctly completed all of the elements of this challenge component. | You have additionally and correctly completed the independent element of this challenge component.
Comments:

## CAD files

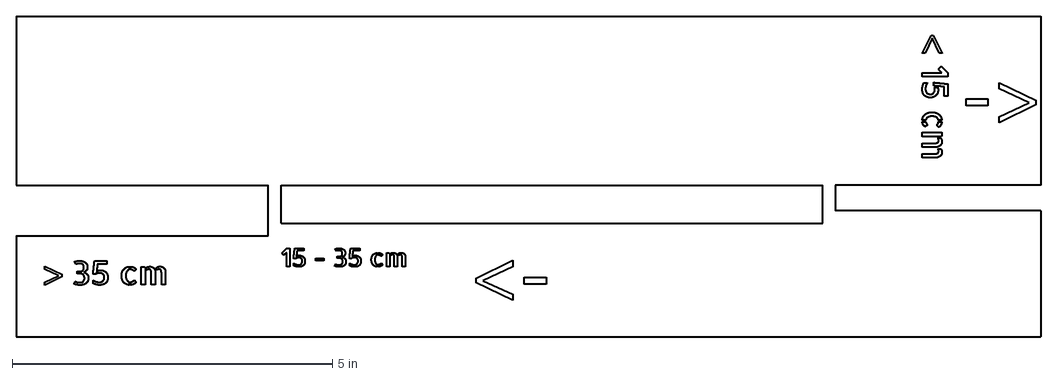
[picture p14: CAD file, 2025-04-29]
Challenge 2: How Far?/Stencils/Challenge 2 Stencil Main.dxf
16.0 x 5.00 in

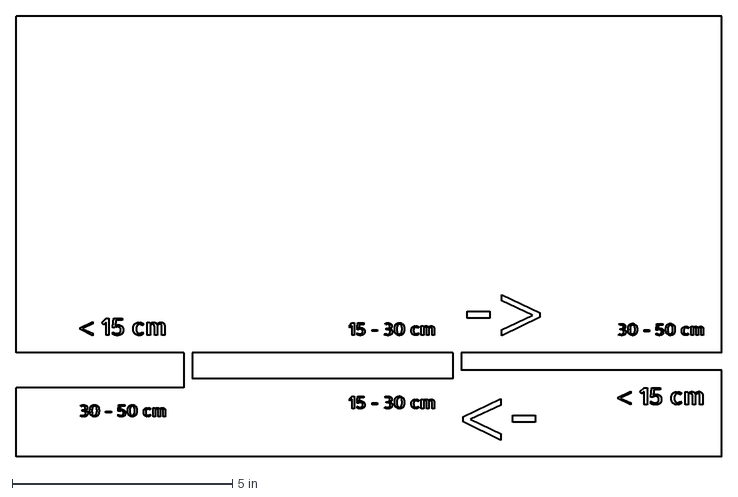
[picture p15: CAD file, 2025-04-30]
Challenge 6: Welcome to Seattle/Stencils/Challenge 6 and 7 Stencil Main.dxf
16.0 x 10.0 in

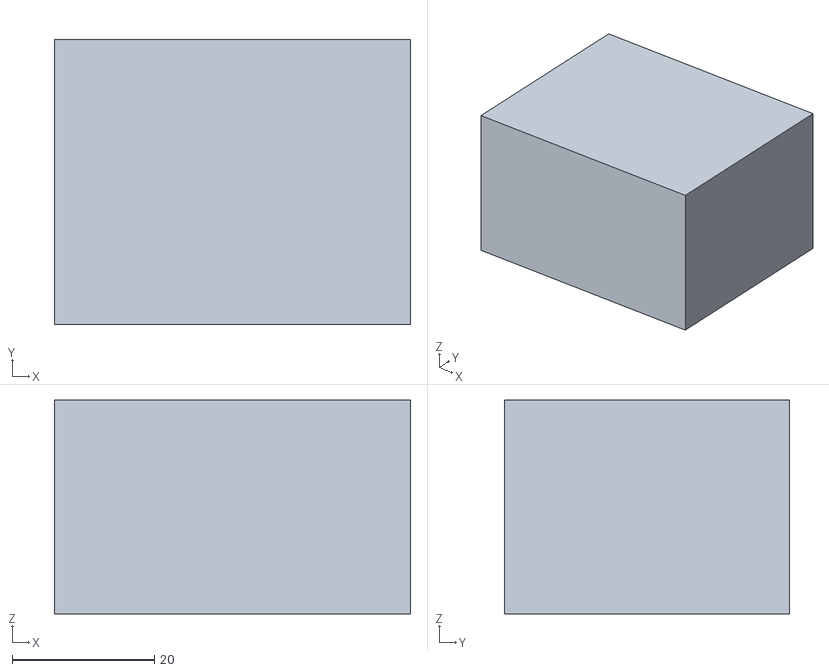
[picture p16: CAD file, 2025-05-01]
Challenge 10: Resupply Mission/3D Prints/Challenge 10 Supply Box.stl
50.0 x 40.0 x 30.0

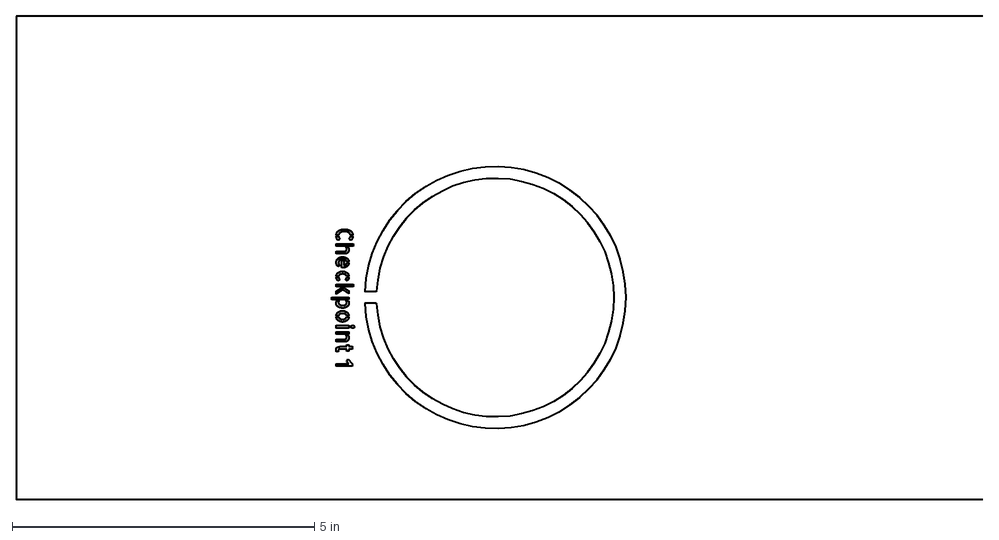
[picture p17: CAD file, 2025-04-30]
Challenge 10: Resupply Mission/Stencils/Challenge 10 Checkpoint 1 Stencil.dxf
16.0 x 8.00 in

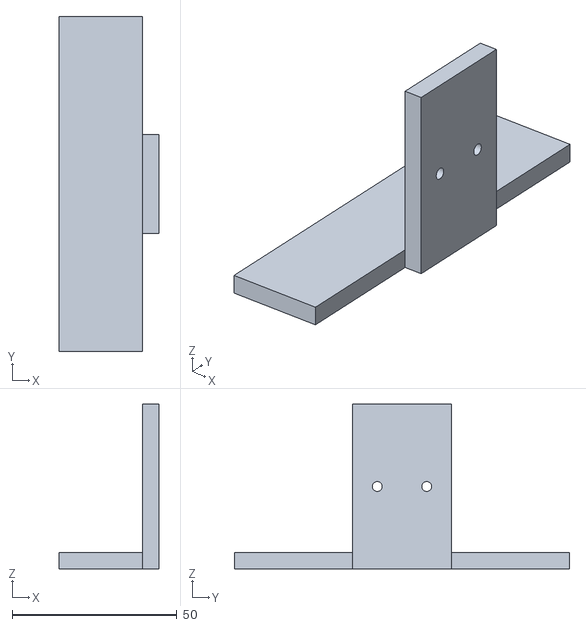
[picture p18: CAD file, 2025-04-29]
Challenge 1: Hercules's Push/3D Prints/Challenge 1 Top Panel Support (X3).stl
30.4 x 101.6 x 50.0

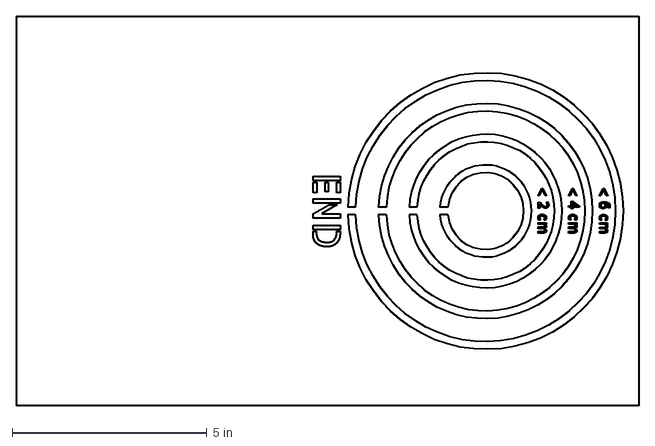
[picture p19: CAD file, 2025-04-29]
Challenge 1: Hercules's Push/Stencils/Challenge 1 End Stencil.dxf
16.0 x 10.0 in

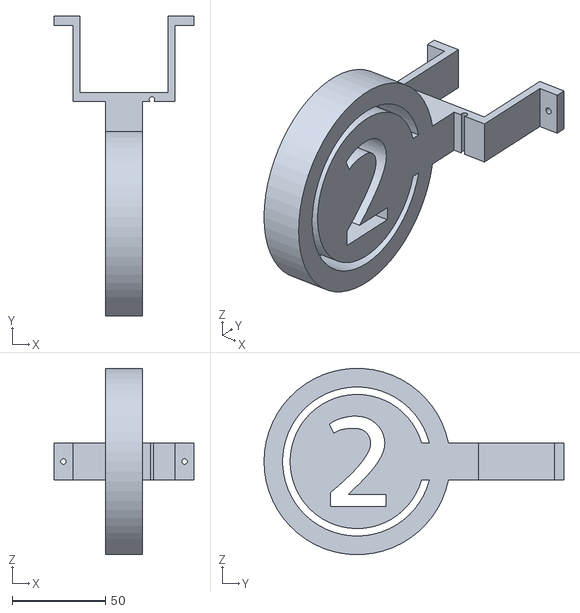
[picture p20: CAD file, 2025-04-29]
Challenge 2: How Far?/3D Prints/Challenge 2 Tag.stl
75.0 x 161.0 x 99.9

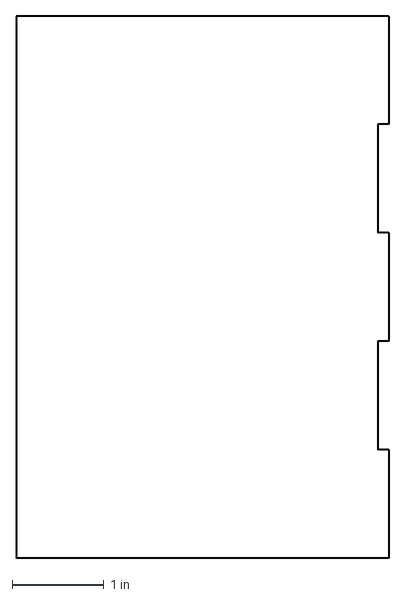
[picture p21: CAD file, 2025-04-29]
Challenge 2: How Far?/Laser Cuts/Challenge 2 Wall 6.dxf
4.06 x 5.91 in

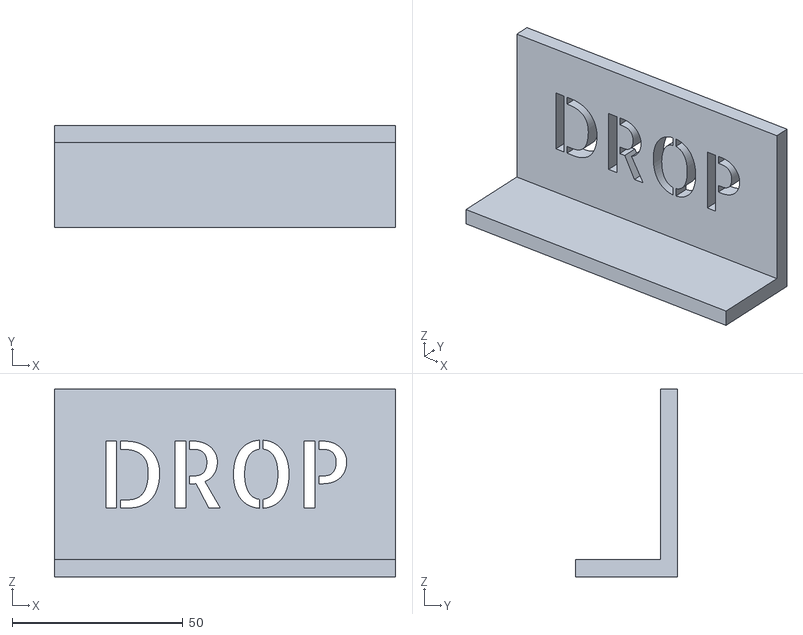
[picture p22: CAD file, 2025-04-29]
Challenge 3: A Rocky Landing/3D Prints/Challenge 3 Drop Sign.stl
100.0 x 30.0 x 55.0

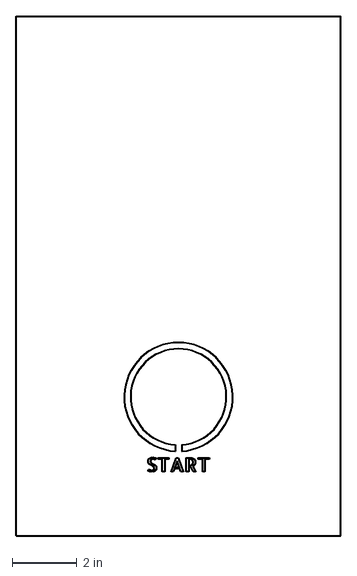
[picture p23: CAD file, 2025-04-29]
Challenge 3: A Rocky Landing/Stencils/Challenge 3 Start Stencil.dxf
10.0 x 16.0 in

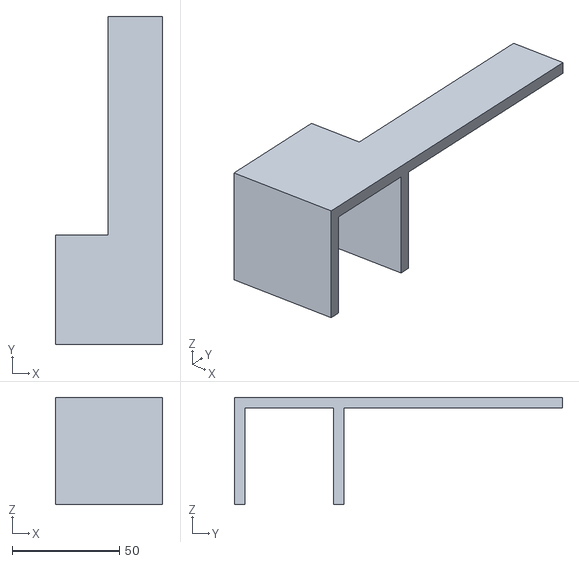
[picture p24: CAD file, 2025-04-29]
Challenge 4: A Way Out/3D Prints/Challenge 4 Bottom Support 2.stl
50.0 x 152.6 x 50.0

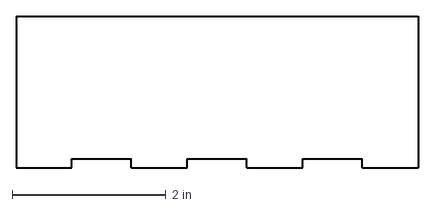
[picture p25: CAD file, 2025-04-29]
Challenge 4: A Way Out/Laser Cuts/Challenge 4 Maze Connecting Wall.dxf
5.23 x 1.97 in

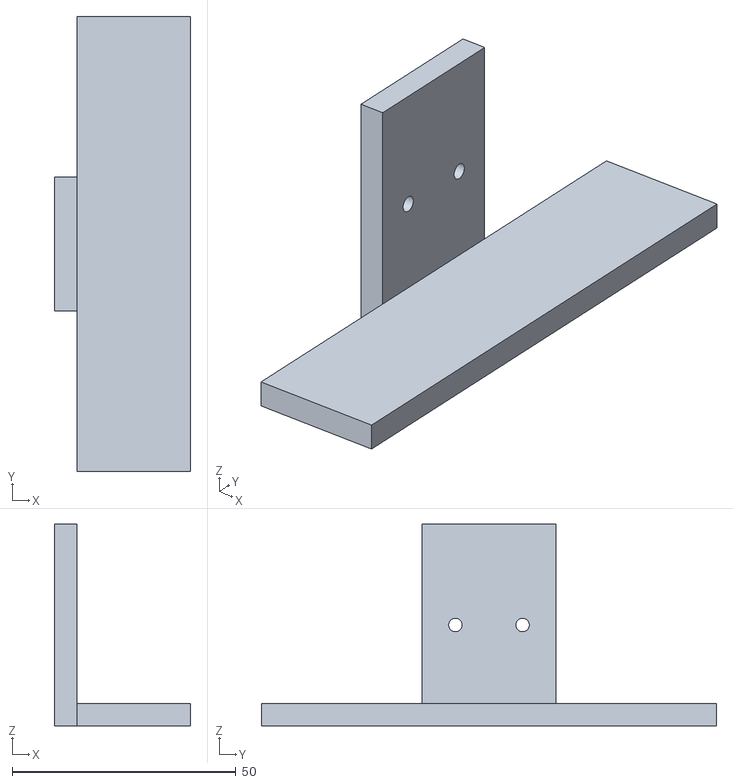
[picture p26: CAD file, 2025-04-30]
Challenge 5: Surface Navigation/3D Prints/Challenge 5 Bottom Support 3.stl
30.4 x 101.6 x 45.0

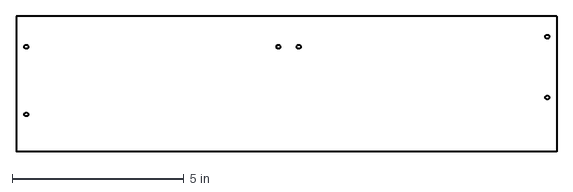
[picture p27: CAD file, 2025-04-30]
Challenge 5: Surface Navigation/Laser Cuts/Challenge 5 Wall 4.dxf
15.7 x 3.94 in

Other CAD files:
Challenge 6: Welcome to Seattle/3D Prints/Challenge 6 and 7 Ramp Support 2.stl
Challenge 6: Welcome to Seattle/Stencils/Challenge 6 and 7 Stencil Top.dxf
Challenge 7: Down the Canyon/3D Prints/Challenge 7 Tag Back Support.stl
Challenge 8: Giving a Gift/3D Prints/Challenge 8 Tag.stl
Challenge 10: Resupply Mission/3D Prints/Challenge 10 Tag Attachment.stl
Challenge 10: Resupply Mission/3D Prints/Challenge 10 Tag.stl
Challenge 10: Resupply Mission/Stencils/Challenge 10 End Stencil.dxf
Challenge 10: Resupply Mission/Stencils/Challenge 10 Start Stencil.dxf
Challenge 1: Hercules's Push/3D Prints/Challenge 1 Bottom Support 1.stl
Challenge 1: Hercules's Push/3D Prints/Challenge 1 Bottom Support 2.stl
Challenge 1: Hercules's Push/3D Prints/Challenge 1 Bottom Support 3.stl
Challenge 1: Hercules's Push/3D Prints/Challenge 1 Bottom Support 4.stl
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

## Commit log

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2025-04-29 Rename Challenge 1 Bottom Support 1.stl to Challenge 1 Bottom Support 1.stl
    [Challenge 1 Bottom Support 1.stl]
2025-04-29 Rename Challenge 1 Bottom Support 2.stl to Challenge 1 Bottom Support 2.stl
    [Challenge 1 Bottom Support 2.stl]
2025-04-29 Rename Challenge 1 Bottom Support 3.stl to Challenge 1 Bottom Support 3.stl
    [Challenge 1 Bottom Support 3.stl]
2025-04-29 Rename Challenge 1 Bottom Support 4.stl to Challenge 1 Bottom Support 4.stl
    [Challenge 1 Bottom Support 4.stl]
2025-04-30 Update and rename Challenge 1 End Stencil.dxf to Challenge 1 End Stencil.dxf
    [Challenge 1 End Stencil.dxf]
2025-04-30 Update and rename Challenge 1 Start Stencil.dxf to Challenge 1 Start Stencil.dxf
    [Challenge 1 Start Stencil.dxf]
2025-04-30 Rename Challenge 1 Tag Back Support.stl to Challenge 1 Tag Back Support.stl
    [Challenge 1 Tag Back Support.stl]
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2025-04-30 Rename Challenge 1 Top Panel Support (X3).stl to Challenge 1 Top Panel Support (X3).stl
    [Challenge 1 Top Panel Support (X3).stl]
2025-04-30 Rename Challenge 2 Bottom Support 1.stl to Challenge 2 Bottom Support 1.stl
    [Challenge 2 Bottom Support 1.stl]
2025-04-30 Rename Challenge 2 Bottom Support 2.stl to Challenge 2 Bottom Support 2.stl
    [Challenge 2 Bottom Support 2.stl]
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2025-04-30 Rename Challenge 2 Rope Attachment 1.stl to Challenge 2 Rope Attachment 1.stl
    [Challenge 2 Rope Attachment 1.stl]
2025-04-30 Rename Challenge 2 Rope Attachment 2.stl to Challenge 2 Rope Attachment 2.stl
    [Challenge 2 Rope Attachment 2.stl]
2025-04-30 Rename Challenge 2 Screwed Support (X2).stl to Challenge 2 Screwed Support (X2).stl
    [Challenge 2 Screwed Support (X2).stl]
2025-04-30 Rename Challenge 2 Side Support (X6).stl to Challenge 2 Side Support (X6).stl
    [Challenge 2 Side Support (X6).stl]
2025-04-30 Update and rename Challenge 2 Stencil Main.dxf to Challenge 2 Stencil Main.dxf
    [Challenge 2 Stencil Main.dxf]
2025-04-30 Update and rename Challenge 2 Stencil Support 1.dxf to Challenge 2 Stencil Support 1.dxf
    [Challenge 2 Stencil Support 1.dxf]
2025-04-30 Update and rename Challenge 2 Stencil Support 2.dxf to Challenge 2 Stencil Support 2.dxf
    [Challenge 2 Stencil Support 2.dxf]
2025-04-30 Rename Challenge 2 Tag Back Support.stl to Challenge 2 Tag Back Support.stl
    [Challenge 2 Tag Back Support.stl]
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2025-04-30 Update and rename Challenge 2 Wall 1.dxf to Challenge 2 Wall 1.dxf
    [Challenge 2 Wall 1.dxf]
2025-04-30 Update and rename Challenge 2 Wall 10.dxf to Challenge 2 Wall 10.dxf
    [Challenge 2 Wall 10.dxf]
2025-04-30 Update and rename Challenge 2 Wall 11.dxf to Challenge 2 Wall 11.dxf
    [Challenge 2 Wall 11.dxf]
2025-04-30 Update and rename Challenge 2 Wall 12.dxf to Challenge 2 Wall 12.dxf
    [Challenge 2 Wall 12.dxf]
2025-04-30 Update and rename Challenge 2 Wall 2.dxf to Challenge 2 Wall 2.dxf
    [Challenge 2 Wall 2.dxf]
2025-04-30 Update and rename Challenge 2 Wall 3.dxf to Challenge 2 Wall 3.dxf
    [Challenge 2 Wall 3.dxf]
2025-04-30 Update and rename Challenge 2 Wall 4.dxf to Challenge 2 Wall 4.dxf
    [Challenge 2 Wall 4.dxf]
2025-04-30 Update and rename Challenge 2 Wall 5.dxf to Challenge 2 Wall 5.dxf
    [Challenge 2 Wall 5.dxf]
2025-04-30 Update and rename Challenge 2 Wall 6.dxf to Challenge 2 Wall 6.dxf
    [Challenge 2 Wall 6.dxf]
2025-04-30 Update and rename Challenge 2 Wall 7.dxf to Challenge 2 Wall 7.dxf
    [Challenge 2 Wall 7.dxf]
2025-04-30 Update and rename Challenge 2 Wall 8.dxf to Challenge 2 Wall 8.dxf
    [Challenge 2 Wall 8.dxf]
2025-04-30 Update and rename Challenge 2 Wall 9.dxf to Challenge 2 Wall 9.dxf
    [Challenge 2 Wall 9.dxf]
2025-04-30 Rename Challenge 3 Bottom Support 1.stl to Challenge 3 Bottom Support 1.stl
    [Challenge 3 Bottom Support 1.stl]
2025-04-30 Rename Challenge 3 Bottom Support 2.stl to Challenge 3 Bottom Support 2.stl
    [Challenge 3 Bottom Support 2.stl]
2025-04-30 Rename Challenge 3 Bottom Support 3.stl to Challenge 3 Bottom Support 3.stl
    [Challenge 3 Bottom Support 3.stl]
2025-04-30 Rename Challenge 3 Bottom Support 4.stl to Challenge 3 Bottom Support 4.stl
    [Challenge 3 Bottom Support 4.stl]
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2025-04-30 Rename Challenge 3 Tag Back Support.stl to Challenge 3 Tag Back Support.stl
    [Challenge 3 Tag Back Support.stl]
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2025-04-30 Update and rename Challenge 3 End Stencil.dxf to Challenge 3 End Stencil.dxf
    [Challenge 3 End Stencil.dxf]
2025-04-30 Update and rename Challenge 3 Start Stencil.dxf to Challenge 3 Start Stencil.dxf
    [Challenge 3 Start Stencil.dxf]
2025-04-30 Rename Challenge 4 Bottom Support 1.stl to Challenge 4 Bottom Support 1.stl
    [Challenge 4 Bottom Support 1.stl]
2025-04-30 Rename Challenge 4 Bottom Support 2.stl to Challenge 4 Bottom Support 2.stl
    [Challenge 4 Bottom Support 2.stl]
2025-04-30 Rename Challenge 4 Bottom Support 3.stl to Challenge 4 Bottom Support 3.stl
    [Challenge 4 Bottom Support 3.stl]
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
